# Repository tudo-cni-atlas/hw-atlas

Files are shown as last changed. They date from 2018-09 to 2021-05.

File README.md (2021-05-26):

hw-altas
================
## Firmware 

The firmware for STM32-based ATLAS anchor and tag nodes is provided as .elf file. 

## Hardware design
A minimal node PCB for the DecaWave DWM1000 module and the STM32F103C8T6 Evaluation Board known as "Blue Pill".



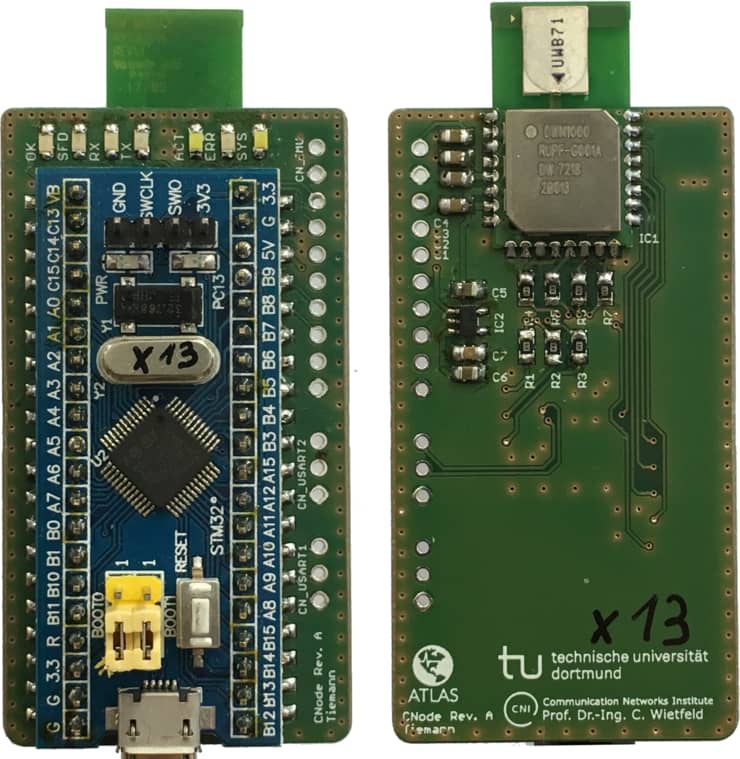
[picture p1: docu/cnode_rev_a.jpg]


### Project schematic:
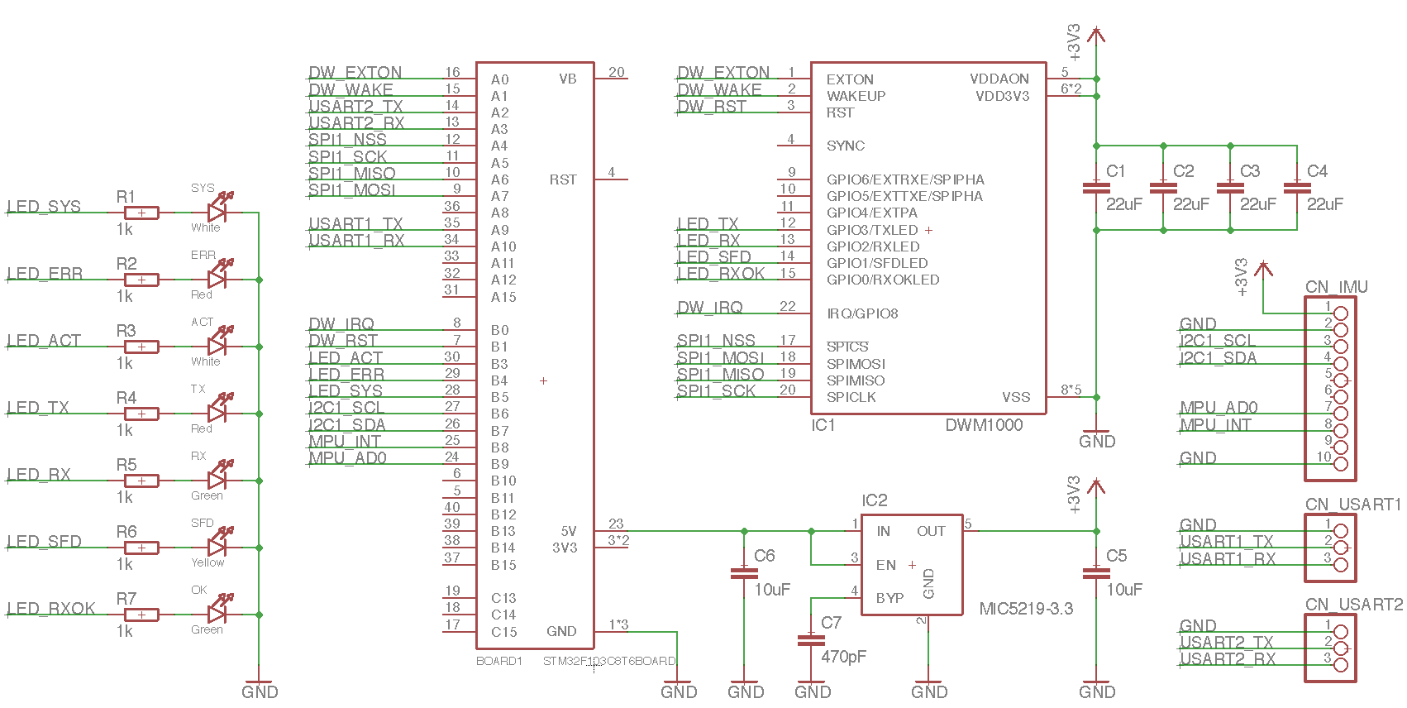
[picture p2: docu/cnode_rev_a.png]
Schematic


### BOM
| Identifier | Type/Value | Quantity | Supplier Id | Supplier | Comment |
| --- | --- | --- | --- | --- | --- |
| R1-R7 | 10 kΩ | 7 | RND 0805 1 1,0K | [Reichelt][reichelt] |
| C7 | 470 pF | 1 | NPO-G0805 470P | [Reichelt][reichelt] |
| C5, C6 | 10 µF | 2 | RND 1500805X1062 | [Reichelt][reichelt] |
| C1-C4 | 22 µF | 4 | X5R 0805 DB 22U | [Reichelt][reichelt] |
| LED_SYS | LED white | 1 | SLO SMD-W0805-0 | [Reichelt][reichelt] |
| LED_ERR | LED red | 1 | OSO LHR974 | [Reichelt][reichelt] |
| LED_SYS | LED white | 1 | SLO SMD-W0805-0 | [Reichelt][reichelt] |
| LED_TX | LED red | 1 | OSO LHR974 | [Reichelt][reichelt] |
| LED_RX | LED green | 1 | OSO LGR971 | [Reichelt][reichelt] |
| LED_SFD | LED yellow | 1 | RND 135-00051 | [Reichelt][reichelt] |
| LED_OK | LED green | 1 | OSO LGR971 | [Reichelt][reichelt] |
| IC1 | DWM1000 | 1 | 1479-1002-1-ND | [Digikey][digikey] |
| IC2 | MIC5219-3.3 | 1 | - | [Aliexpress][aliexpress] |
| BOARD1 | STM32 Eval Board | 1 | - | [Aliexpress][aliexpress] |

[reichelt]: http://www.reichelt.de
[mouser]: http://mouser.com
[aliexpress]: http://www.aliexpress.com
[digikey]: http://www.digikey.de

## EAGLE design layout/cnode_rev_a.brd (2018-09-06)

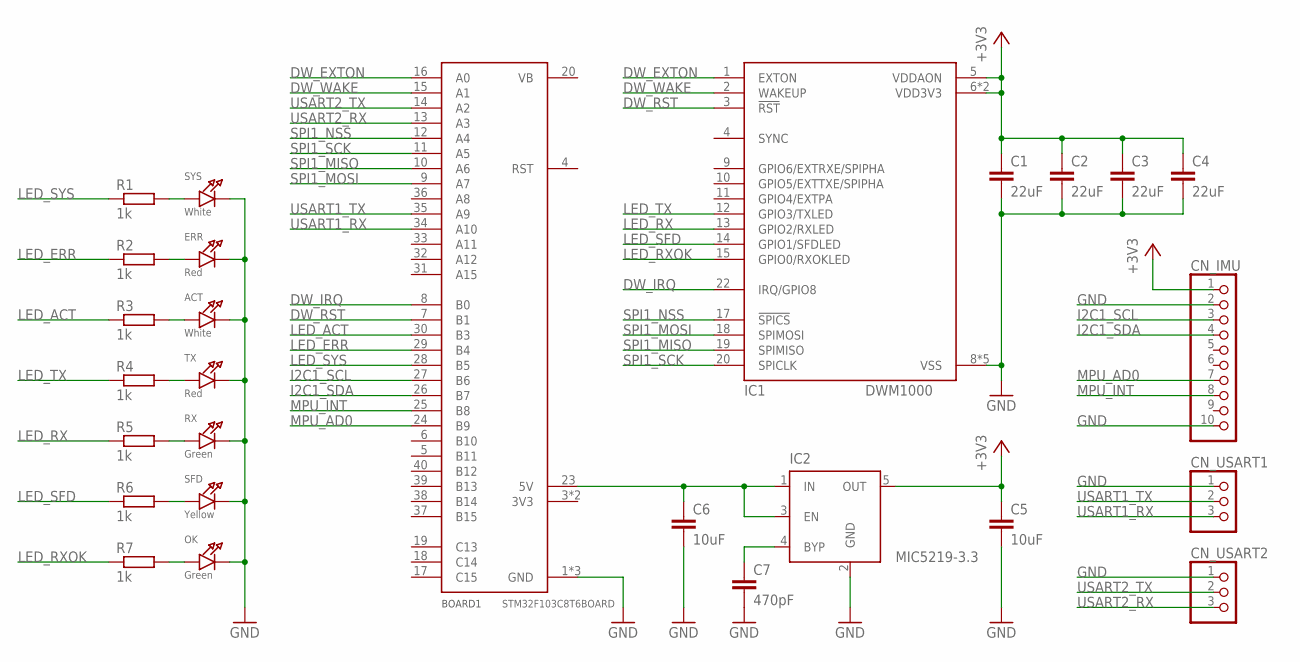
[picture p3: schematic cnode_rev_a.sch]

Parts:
ACT: White; CHIPLED_0805_NOOUTLINE
BOARD1: STM32F103C8T6BOARD
C1, C2, C3, C4: 22uF; C0805
C5, C6: 10uF; C0805
C7: 470pF; C0805
CN_IMU: HEADER-1X10ROUND; 1X10_ROUND
CN_USART1, CN_USART2: HEADER-1X3ROUND; 1X03_ROUND
ERR: Red; CHIPLED_0805_NOOUTLINE
IC1: DWM1000
IC2: MIC5219-3.3; SOT23-5
OK: Green; CHIPLED_0805_NOOUTLINE
R1, R2, R3, R4, R5, R6, R7: 1k; R0805
RX: Green; CHIPLED_0805_NOOUTLINE
SFD: Yellow; CHIPLED_0805_NOOUTLINE
SYS: White; CHIPLED_0805_NOOUTLINE
TX: Red; CHIPLED_0805_NOOUTLINE

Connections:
+3V3: C1.1, C2.1, C3.1, C4.1, C5.1, CN_IMU.1, IC1.5 (VDDAON), IC1.6 (VDD3V3), IC1.7 (VDD3V3), IC2.5 (OUT)
DW_EXTON: BOARD1.16 (A0), IC1.1 (EXTON)
DW_IRQ: BOARD1.8 (B0), IC1.22 (IRQ/GPIO8)
DW_RST: BOARD1.7 (B1), IC1.3 (!RST)
DW_WAKE: BOARD1.15 (A1), IC1.2 (WAKEUP)
GND: ACT.C, BOARD1.1 (GND), BOARD1.2 (GND), BOARD1.22 (GND), C1.2, C2.2, C3.2, C4.2, C5.2, C6.2, C7.2, CN_IMU.2, CN_IMU.10, CN_USART1.1, CN_USART2.1, ERR.C, IC1.8 (VSS), IC1.16 (VSS), IC1.21 (VSS), IC1.23 (VSS), IC1.24 (VSS), IC2.2 (GND), OK.C, RX.C, SFD.C, SYS.C, TX.C
I2C1_SCL: BOARD1.27 (B6), CN_IMU.3
I2C1_SDA: BOARD1.26 (B7), CN_IMU.4
LED_ACT: BOARD1.30 (B3), R3.1
LED_ERR: BOARD1.29 (B4), R2.1
LED_RX: IC1.13 (GPIO2/RXLED), R5.1
LED_RXOK: IC1.15 (GPIO0/RXOKLED), R7.1
LED_SFD: IC1.14 (GPIO1/SFDLED), R6.1
LED_SYS: BOARD1.28 (B5), R1.1
LED_TX: IC1.12 (GPIO3/TXLED), R4.1
MPU_AD0: BOARD1.24 (B9), CN_IMU.7
MPU_INT: BOARD1.25 (B8), CN_IMU.8
unnamed: R5.2, RX.A
unnamed: R4.2, TX.A
unnamed: ACT.A, R3.2
unnamed: ERR.A, R2.2
unnamed: R1.2, SYS.A
unnamed: BOARD1.23 (5V), C6.1, IC2.1 (IN), IC2.3 (EN)
unnamed: C7.1, IC2.4 (BYP)
unnamed: R6.2, SFD.A
unnamed: OK.A, R7.2
SPI1_MISO: BOARD1.10 (A6), IC1.19 (SPIMISO)
SPI1_MOSI: BOARD1.9 (A7), IC1.18 (SPIMOSI)
SPI1_NSS: BOARD1.12 (A4), IC1.17 (!SPICS)
SPI1_SCK: BOARD1.11 (A5), IC1.20 (SPICLK)
USART1_RX: BOARD1.34 (A10), CN_USART1.3
USART1_TX: BOARD1.35 (A9), CN_USART1.2
USART2_RX: BOARD1.13 (A3), CN_USART2.3
USART2_TX: BOARD1.14 (A2), CN_USART2.2

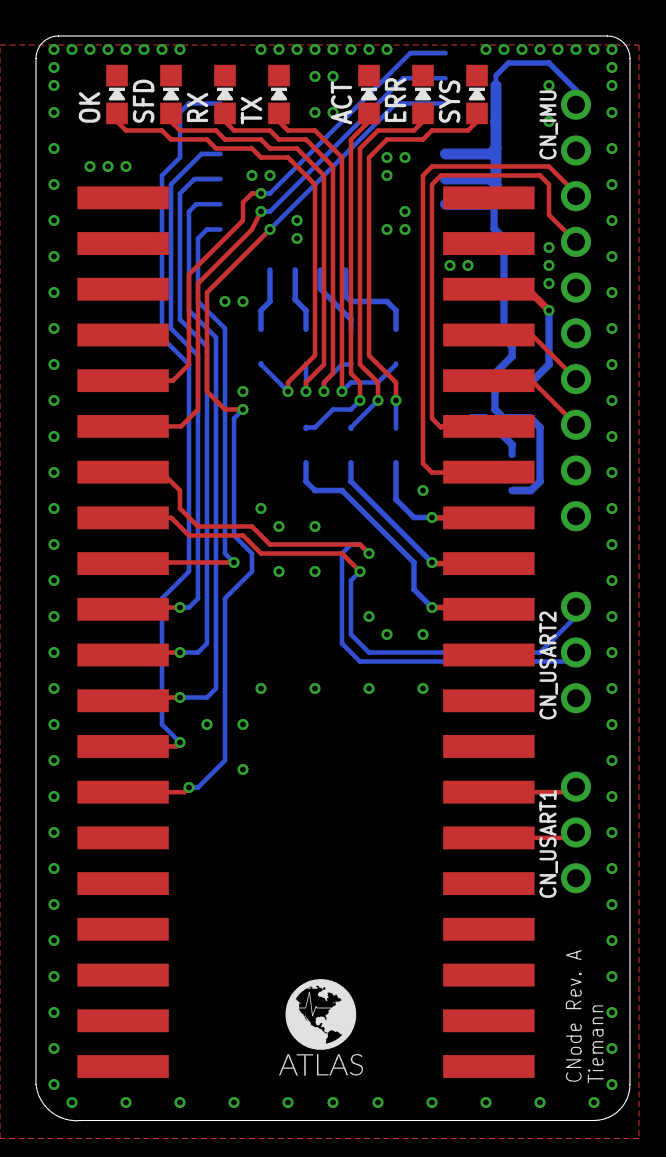
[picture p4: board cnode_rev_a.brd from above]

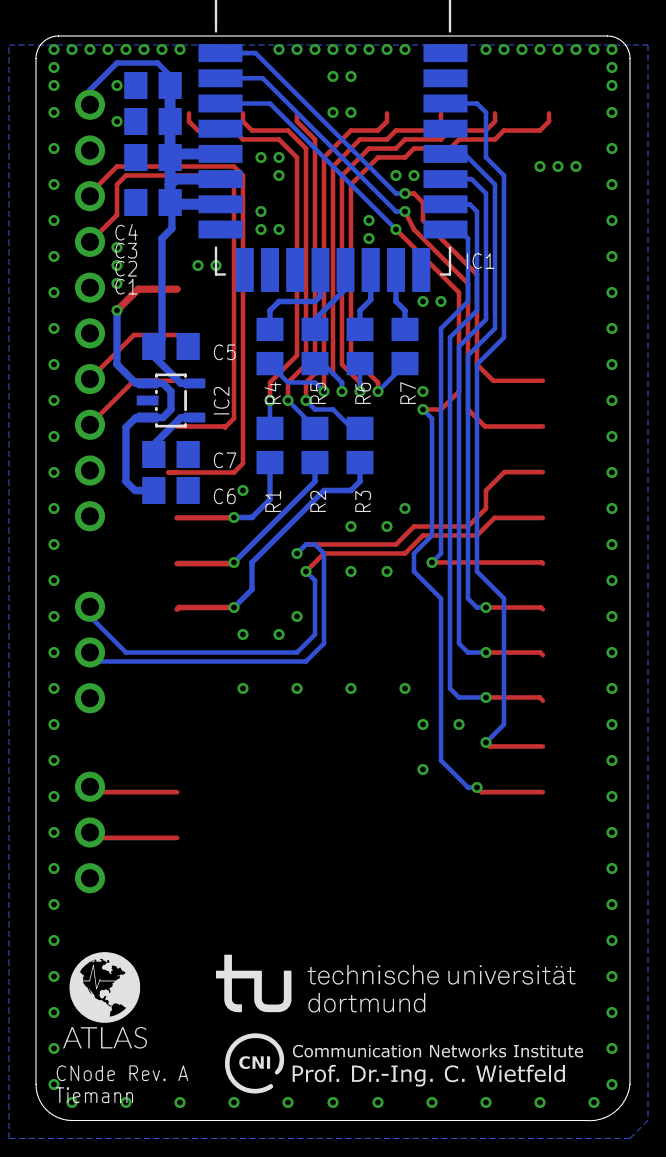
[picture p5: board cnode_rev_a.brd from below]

Board: 2 copper layers, 33.0 x 60.3 mm, 31 parts (19 on the bottom side), 34 nets.

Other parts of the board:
U$2, U$4: ATLAS_LOGO_5MM
U$5: CNI-BANNER-EN_20MM
U$6: TU-BANNER_20MM

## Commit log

2018-09-06 Updated to STM32-based node for ATLAS 2.0 release
    [cnode_rev_a.brd, cnode_rev_a.sch, node_bot_rev_a.FCStd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]
2018-09-06 Added picture of assembled board

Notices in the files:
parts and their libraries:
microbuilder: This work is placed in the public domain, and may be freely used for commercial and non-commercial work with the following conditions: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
